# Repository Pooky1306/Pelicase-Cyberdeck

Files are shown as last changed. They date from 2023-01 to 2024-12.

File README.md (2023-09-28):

# Pelicase-Cyberdeck
Inspired by Jay Doscher awesome work : https://doscher.com/

Deck3-2 (Large)

Cyberdeck made around Pelicases 1150 and 1300, here are custom keyboard PCB files, cad files, firmware,etc.

CAD files may be over-engineered but are made to fit a Prusa mini+ (180x180mm, print diagonally the longest ones))

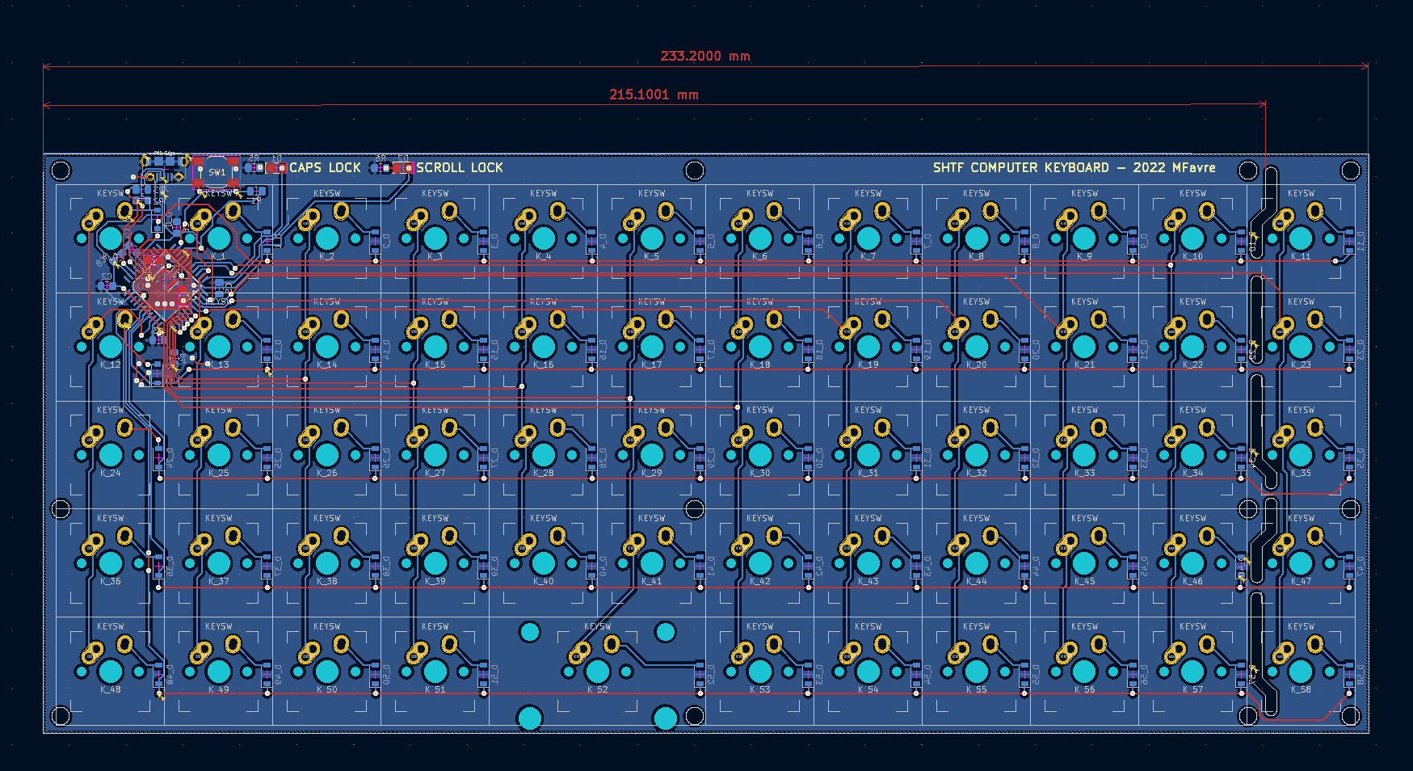
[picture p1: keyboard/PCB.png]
PCB


_1100956 (Large)

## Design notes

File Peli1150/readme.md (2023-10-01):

Files for Peli 1150

I quickly changed the pi4 for a rock 5b
For power I use a 18650 Lithium Battery Shield found on aliex and co

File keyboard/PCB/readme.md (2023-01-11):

PCB files for the custom keyboard made with kicad 6.0

Manufacturing files formated for JLCPCB including assembly and soldering (onloy back layer)

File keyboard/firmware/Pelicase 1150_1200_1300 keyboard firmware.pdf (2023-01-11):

# Pelicase 1150 / 1200 /1300 Mechanical keyboard

Infos:

Current way of doing it isn’t the best: it uses https://kbfirmware.com/ which is a bit outdated and not the most practical but does the job.

I will use QMK (https://config.qmk.fm) later but I first need to learn how to create a 5x11 layout with the correct pining.

Firmware file is uploaded to the board using https://github.com/qmk/qmk_toolbox

Firmware file creation

So go to https://kbfirmware.com/

Paste the following layout:
(this can be edited before import, it’s a pretty straight forward layout but doesn’t contains layers, special functions, etc)

[{a:7},"Esc","1","2","3","4","5","6","7","8","9","0"],
["Tab","Q","W","E","R","T","Z","U","I","O","P"],
["Caps","A","S","D","F","G","H","J","K","L","Back Space"], ["Shift","Y","X","C","V","B","N","M",{a:5},";\n,",":\n.",{a:7},"Return"], ["Ctrl","Alt","Super","&dArr;",{w:2},"","&uArr;","&larr;","&darr;","&uarr;","&rarr;"]

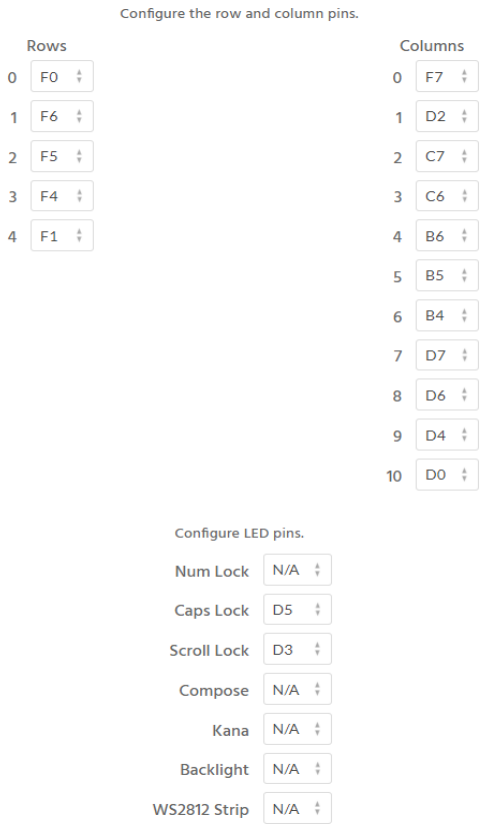
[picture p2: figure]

Wiring tab should be set to:

Rows 5
Columns 11
Diode direction Col to row

Got to Pins tab:
Controller is a 32u4
Configure as follow -------------------------------->

Next keymap tab is where everything happens.

You can select a key and remap it by pressing the new one on your keyboard.
If you select a key and click again on it on the bottom under “Configure the selected key” you’ll have access to all the special functions including the layer change, etc.
Take some time to read the linked QMK docs at the bottom.

Macros and Quantum tabs should be left as they are. Unless you know what you’re doing.

Settings let you export a JSON file of the layout which can then be formatted to be copy/paste as in the first step for later modifications.
Don’t mind the soft reset warning, the pcb as a hard wired reset one.

Last step is Compile tab where you can download the .hex file which is the compiled code that will be uploaded on the atmega 32u4

Firmware upload

Install and Run the QMK toolbox software (install drivers too !)

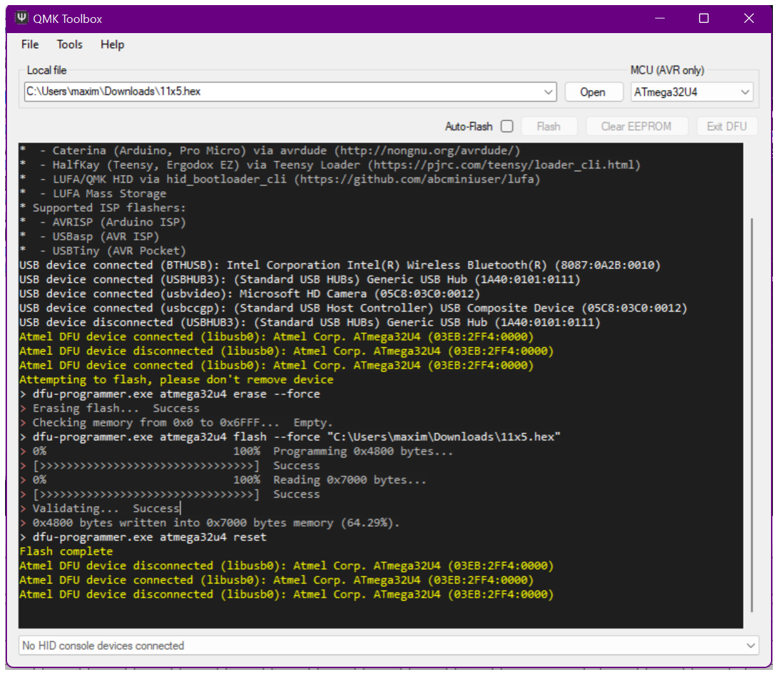
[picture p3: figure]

- Drag or select your previously
downloaded hex file
- Select the correct MCU (still
32u4)
- Plug the board to the computer while pressing the reset button, then release it.
- A yellow line should appear regarding an Atmel DFU device connected. If not, try another cable (I had some issue with some longer ones)
- Then clear EEPROM and Flash (or use “Auto-flash” feature)
- After everything is completed, unplug and replug the keyboard
- You can then use the key tester under the tools tab to check if every switch is working properly.

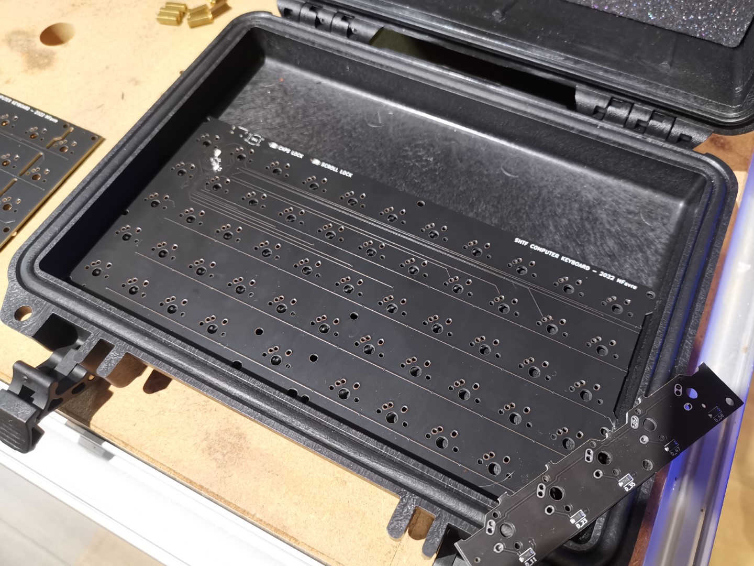
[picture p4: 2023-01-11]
keyboard/IMG_20221125_212838 (Large).jpg

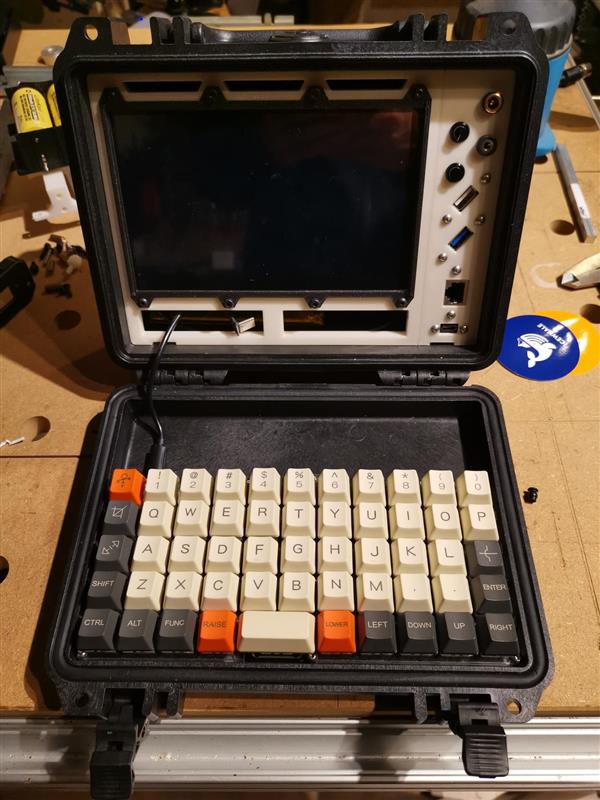
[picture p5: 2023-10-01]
Peli1150/0271e649-5dd4-45ba-a3d6-399fec9d43ff.jpg

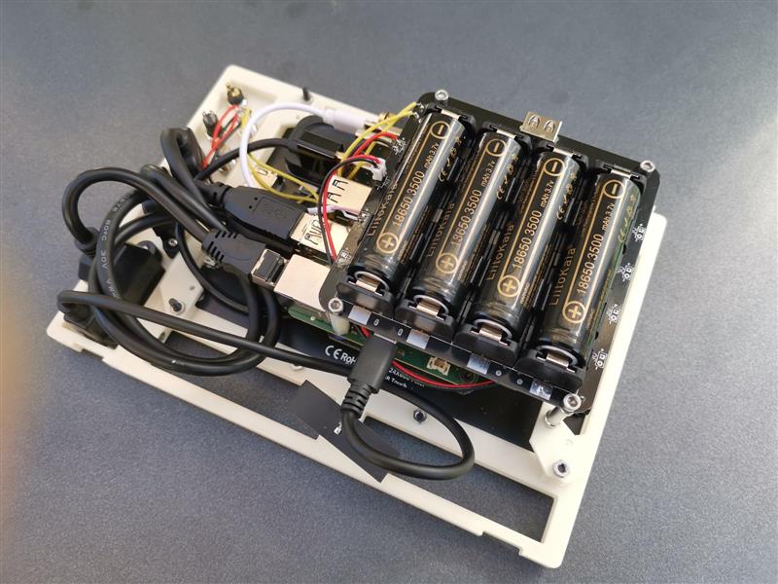
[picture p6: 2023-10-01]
Peli1150/b24f2c66-4a51-46b4-bde6-3758cdaf1261.jpg

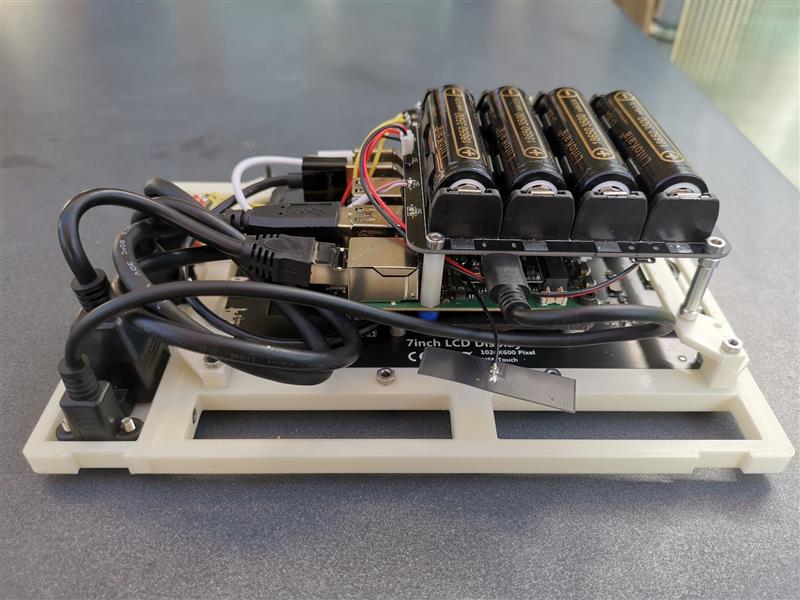
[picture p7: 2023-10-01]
Peli1150/520f1e82-266e-4577-b640-53f9d0e34498.jpg

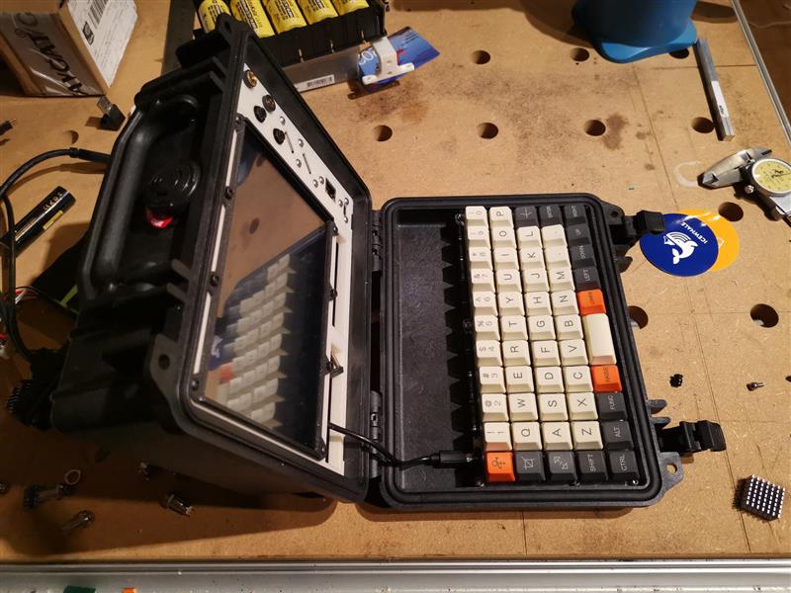
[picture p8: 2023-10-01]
Peli1150/554980b8-3844-488c-8d68-8198313a5d0e.jpg

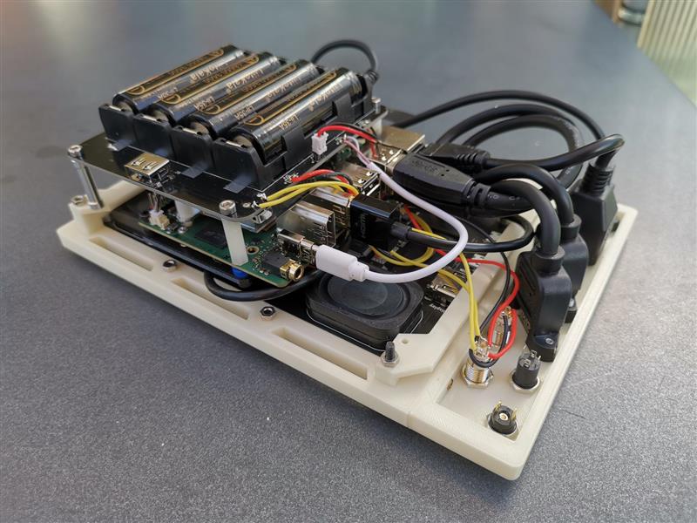
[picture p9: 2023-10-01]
Peli1150/20530fff-dde9-442d-8553-078ab6f21ee3.jpg

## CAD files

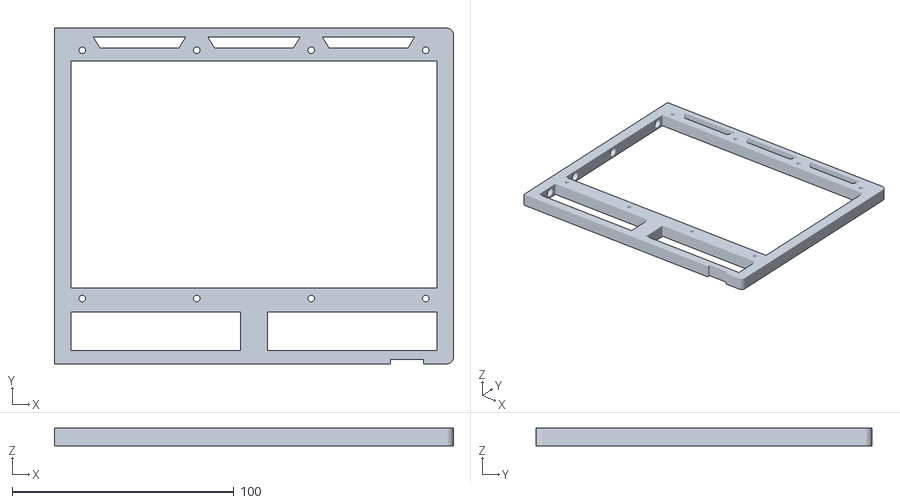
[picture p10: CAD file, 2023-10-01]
Peli1150/STL/main frame.stl
180.0 x 151.5 x 8.00

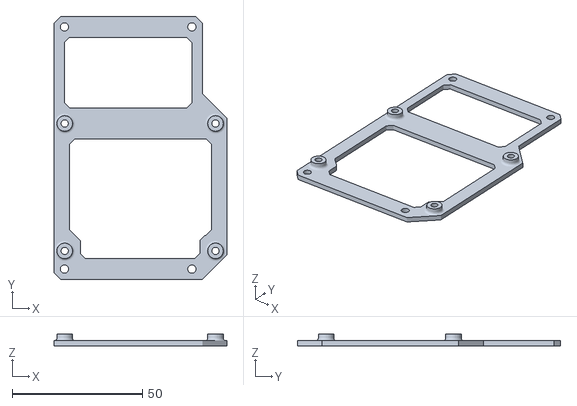
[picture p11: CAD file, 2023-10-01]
Peli1150/STL/pi4 to rock 5b adapter.stl
66.5 x 101.2 x 4.50

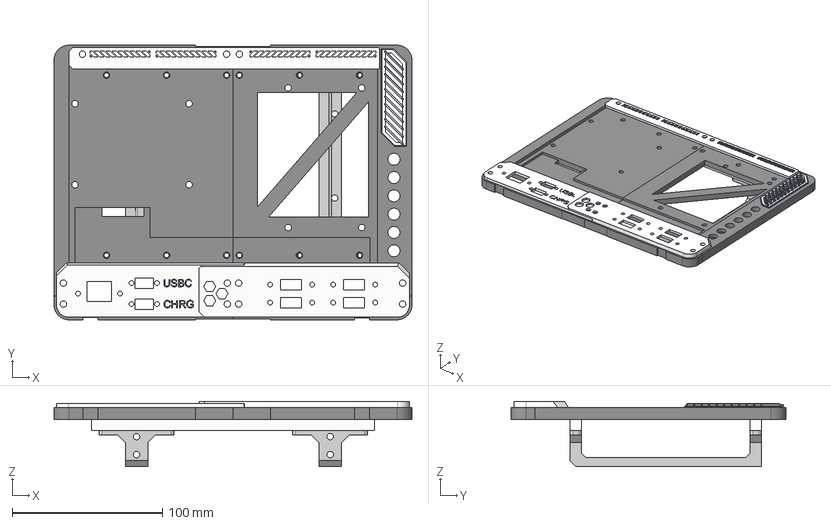
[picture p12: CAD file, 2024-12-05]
Peli1300/1300 Screen mount v1.step
238.5 x 183.0 x 43.5 mm
1300 Screen mount_Component7 v1

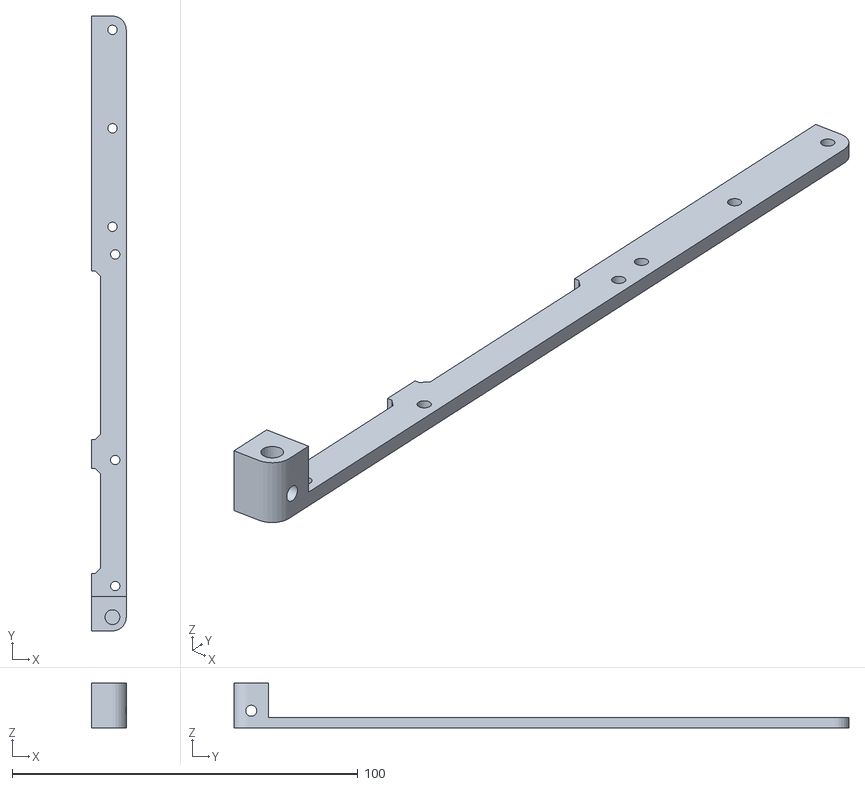
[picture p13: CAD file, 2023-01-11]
Peli1300/keyboard frame/keyboard frame R.stl
10.0 x 178.0 x 13.0

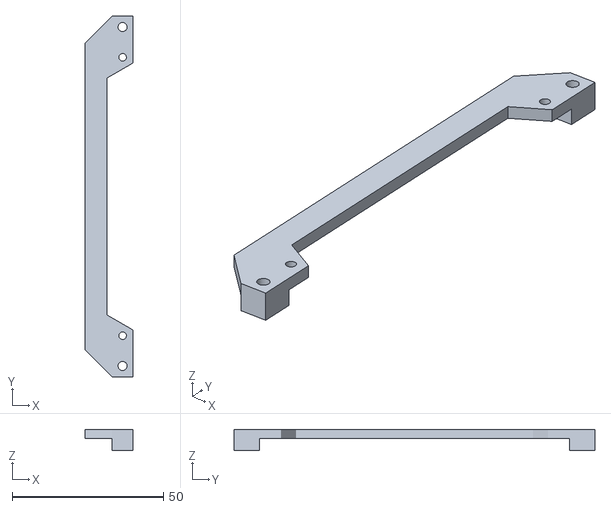
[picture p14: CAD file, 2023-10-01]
Peli1150/STL/screen holder IO side.stl
16.0 x 119.3 x 7.00

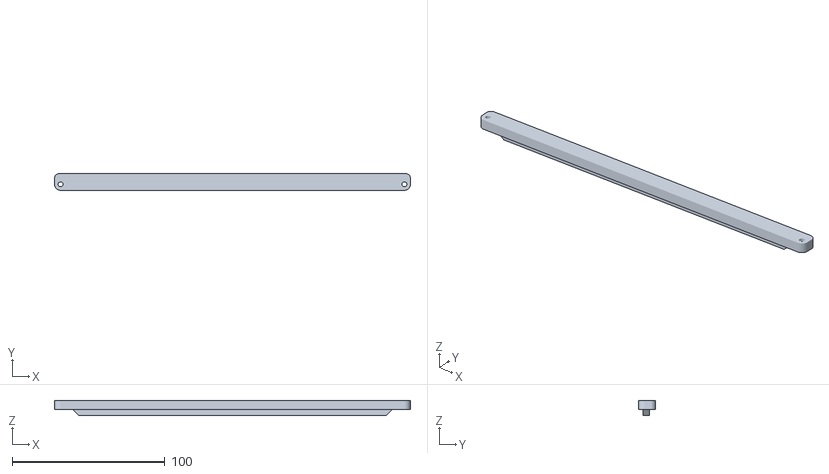
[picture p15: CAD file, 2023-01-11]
Peli1300/keyboard frame/keyboard frame Bottom.stl
233.3 x 11.0 x 10.0

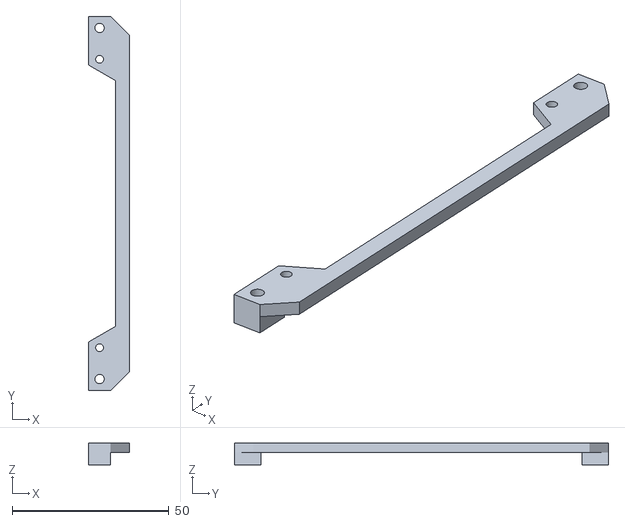
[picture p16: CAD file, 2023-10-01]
Peli1150/STL/screen holder.stl
13.0 x 119.3 x 7.00

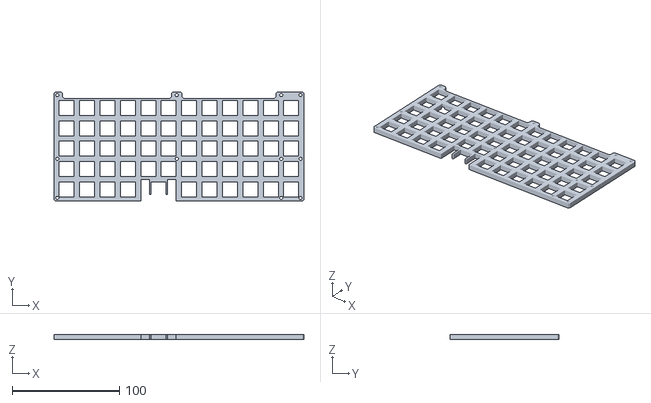
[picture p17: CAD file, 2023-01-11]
Peli1300/keyboard frame/keyboard Switch Spacer.stl
233.3 x 102.0 x 5.00

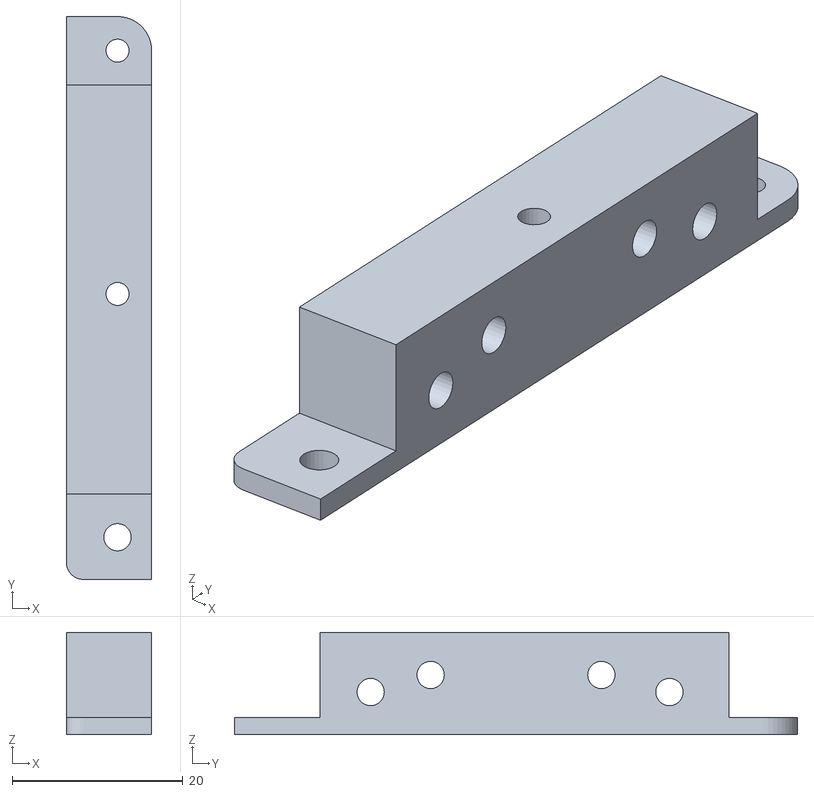
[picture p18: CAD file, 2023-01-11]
Peli1300/keyboard frame/keyboard frame Top L.stl
10.0 x 65.9 x 12.0

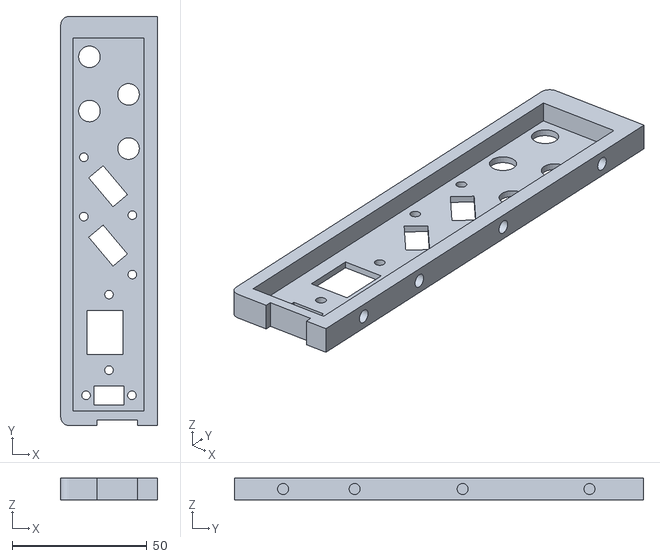
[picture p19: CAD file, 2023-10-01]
Peli1150/STL/IO frame.stl
35.8 x 151.5 x 8.00

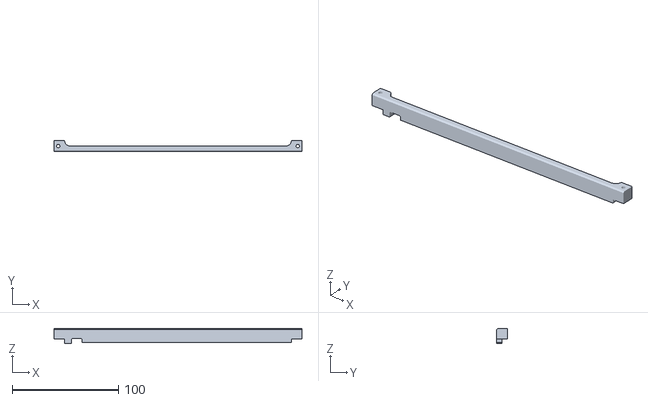
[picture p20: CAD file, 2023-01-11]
Peli1300/keyboard frame/keyboard frame Middle.stl
233.3 x 10.00 x 14.0

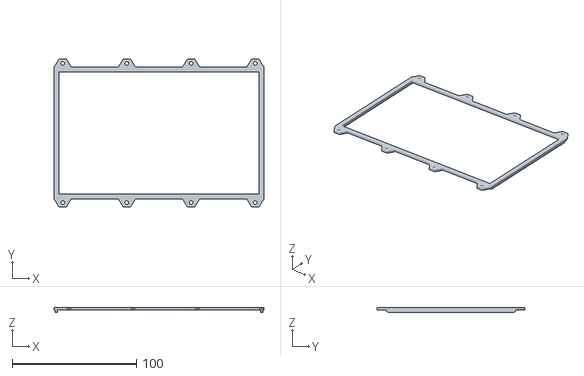
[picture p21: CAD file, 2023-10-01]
Peli1150/STL/Screen face.stl
169.0 x 119.0 x 4.00

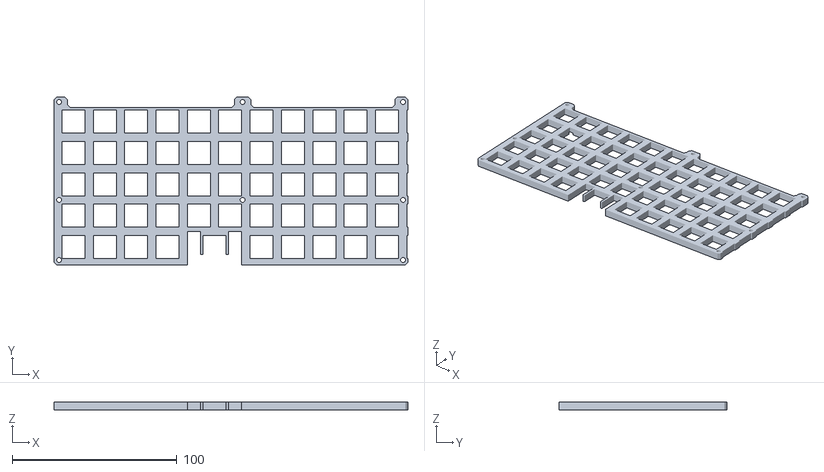
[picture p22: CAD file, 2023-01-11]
Peli1150/STL/keyboard Switch Spacer.stl
215.1 x 102.0 x 5.00

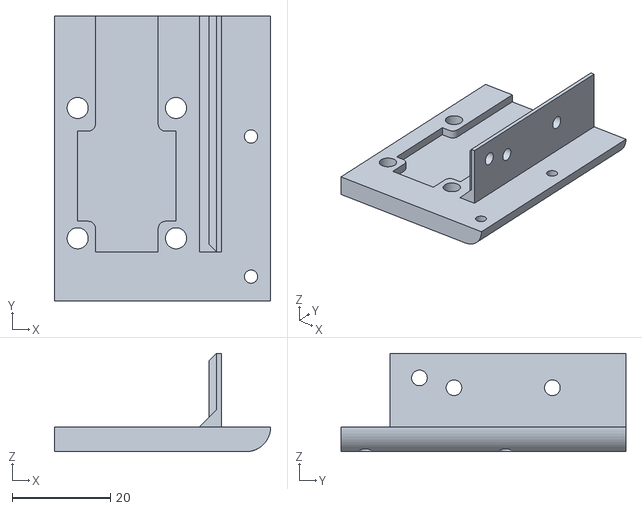
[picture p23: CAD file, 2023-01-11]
Peli1300/keyboard frame/keyboard frame Joystick Mount.stl
44.0 x 57.9 x 20.0

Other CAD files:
Peli1300/keyboard frame/keyboard frame Top R.stl
Peli1300/keyboard frame/keyboard frame L.stl
Peli1300/keyboard frame/keyboard frame Top.stl
